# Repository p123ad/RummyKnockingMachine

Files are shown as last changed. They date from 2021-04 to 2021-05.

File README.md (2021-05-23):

# RummyKnockingMachine
 This is an Arduino-based machine that detects multiple button presses and symbolizes the first button pressed by a shining LED.
 
 It consists of 6 buttons, 6 leds and 1 piezo speaker connected to an Arduino Uno via a self designed Arduino Uno Shield.
 
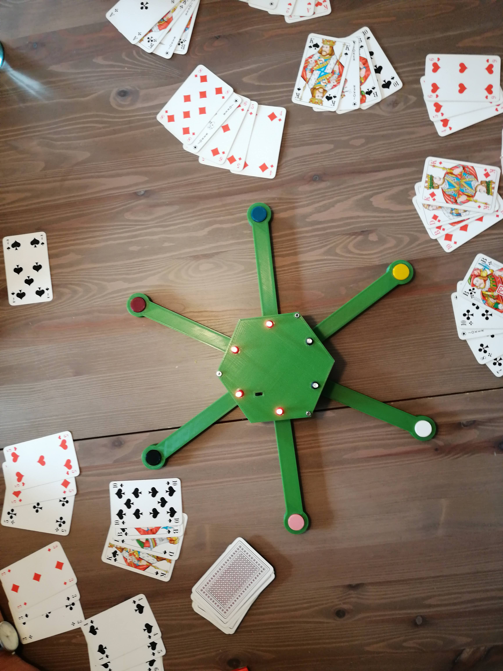
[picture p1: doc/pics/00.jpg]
RummyKnockingMachine


You can find all stls in the parts folder. They can be printed on most common 3d printers (used and stock ender 5).

The circuit diagram, breadboard diagram and the gerber files for this project are located in the electronics folder.

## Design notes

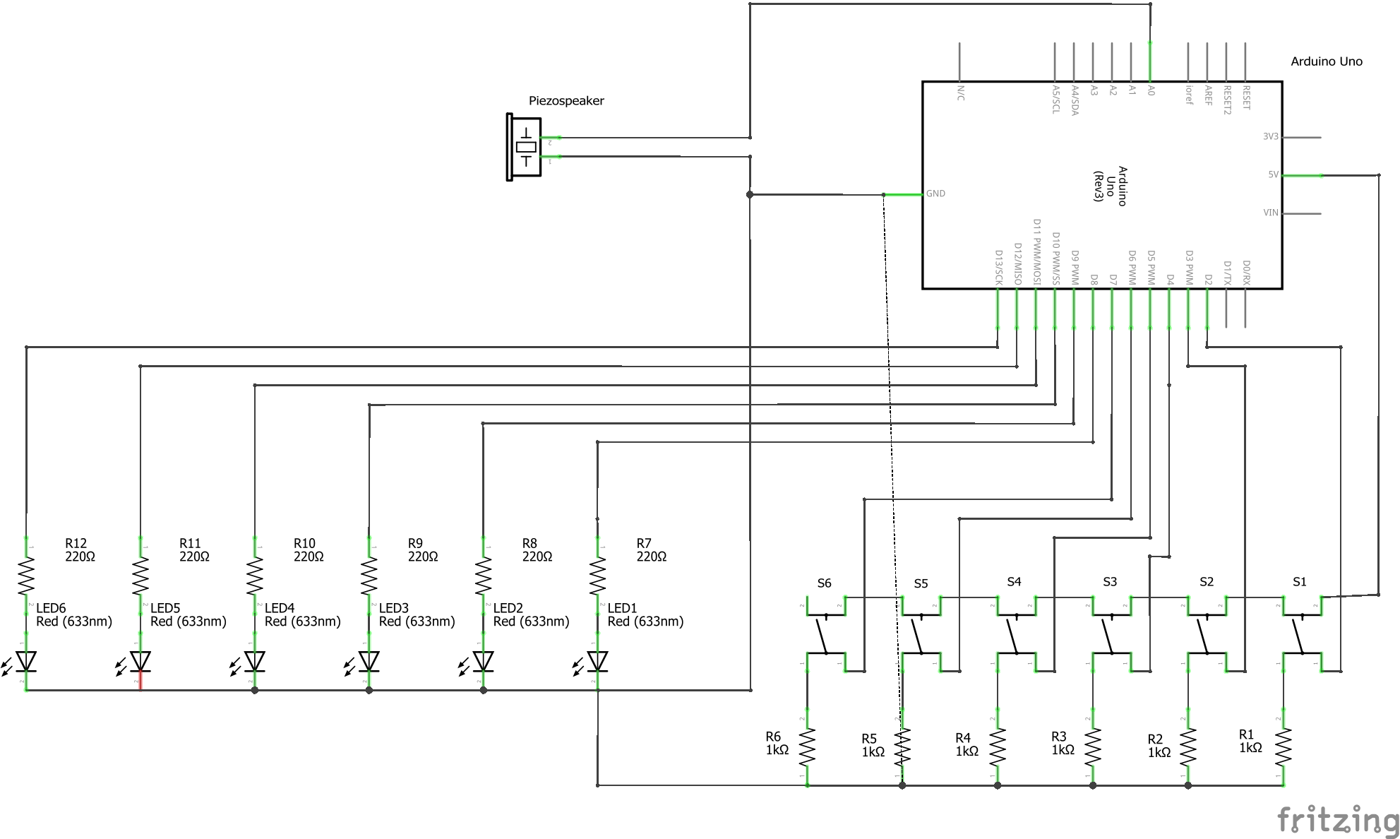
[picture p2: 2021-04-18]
electronics/circuit_diagram.png

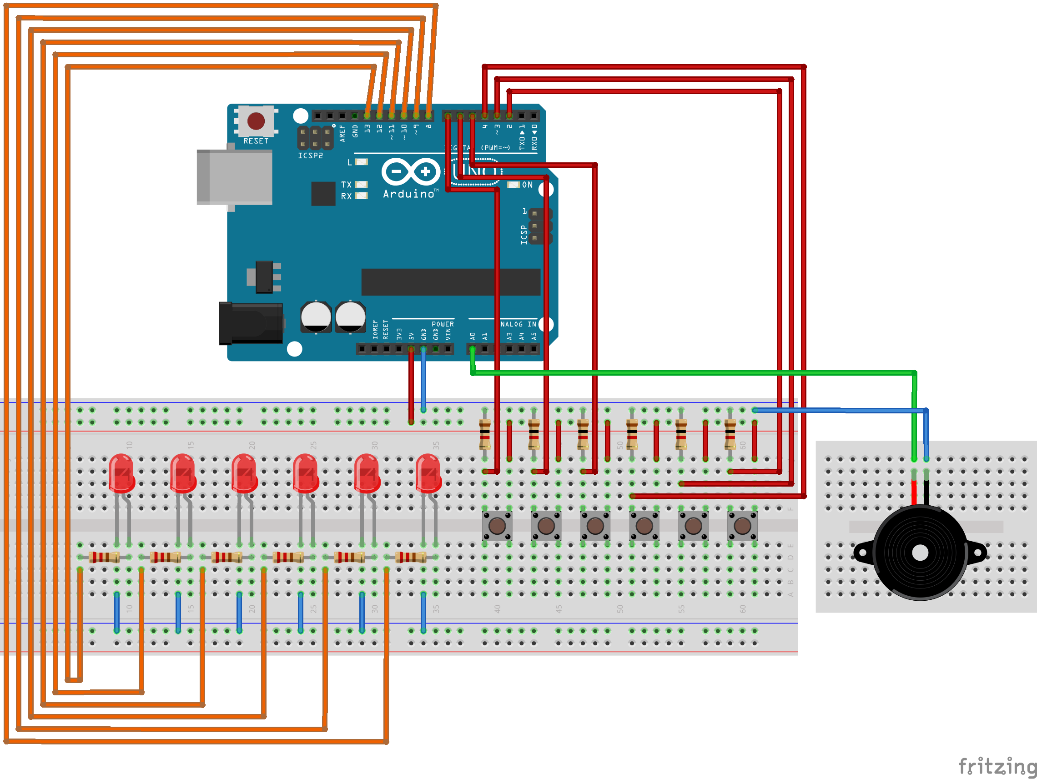
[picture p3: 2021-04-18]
electronics/breadboard_diagram.png

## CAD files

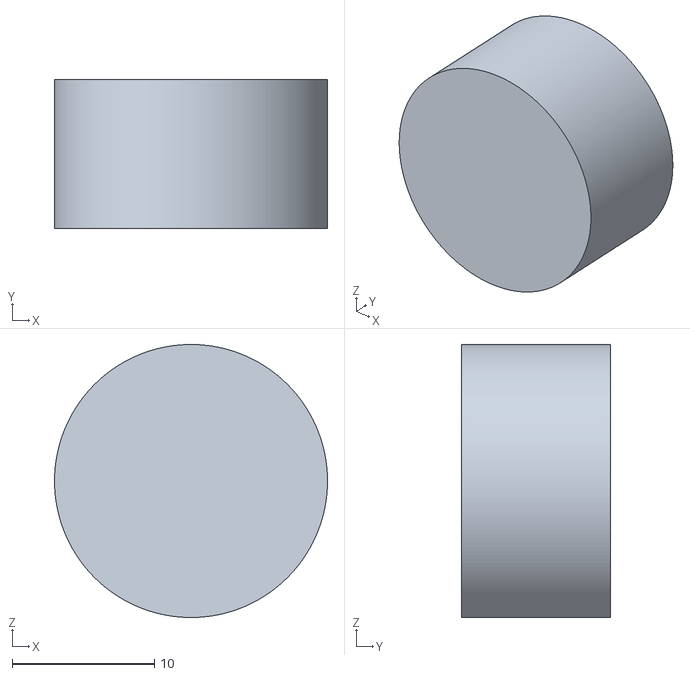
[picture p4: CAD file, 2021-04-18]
parts/stl/Knopf.stl
19.2 x 10.5 x 19.2

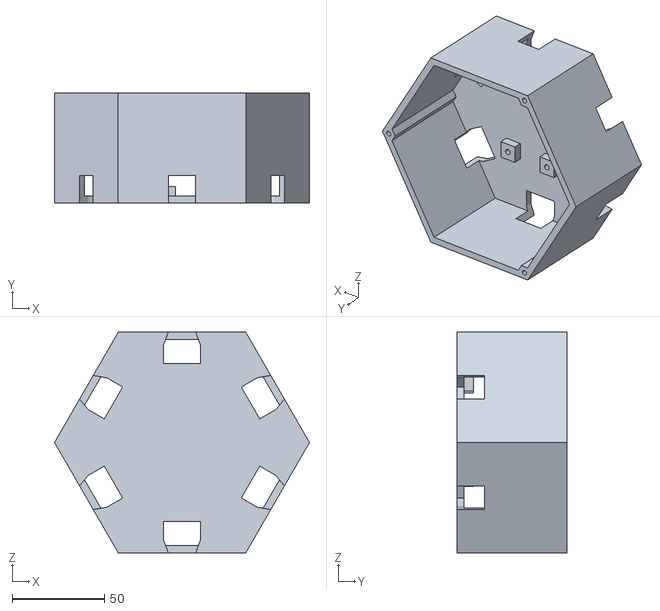
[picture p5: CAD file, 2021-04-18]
parts/stl/Box.stl
138.6 x 60.0 x 120.0

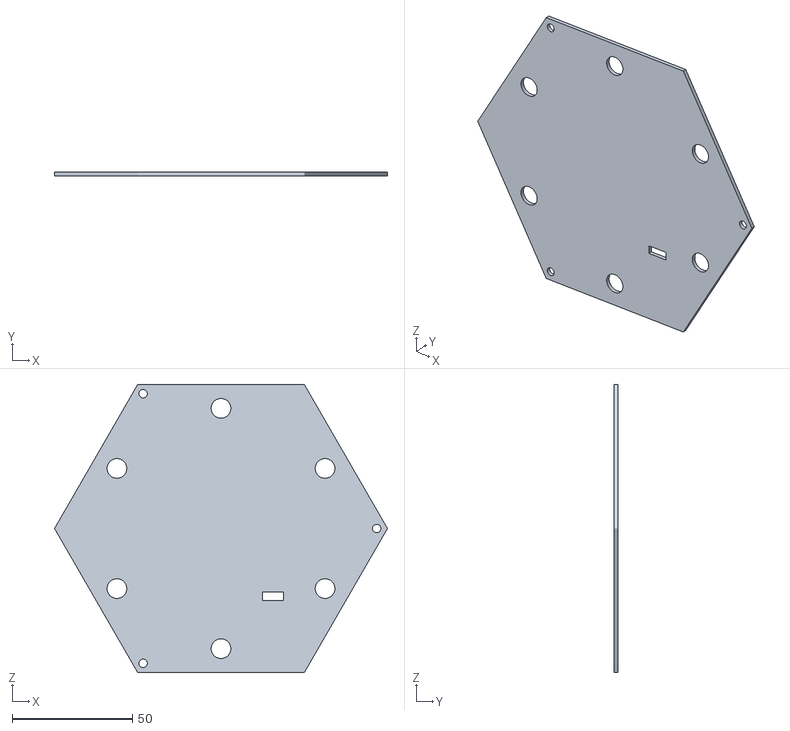
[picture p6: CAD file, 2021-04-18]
parts/stl/Lid.stl
138.6 x 1.60 x 120.0

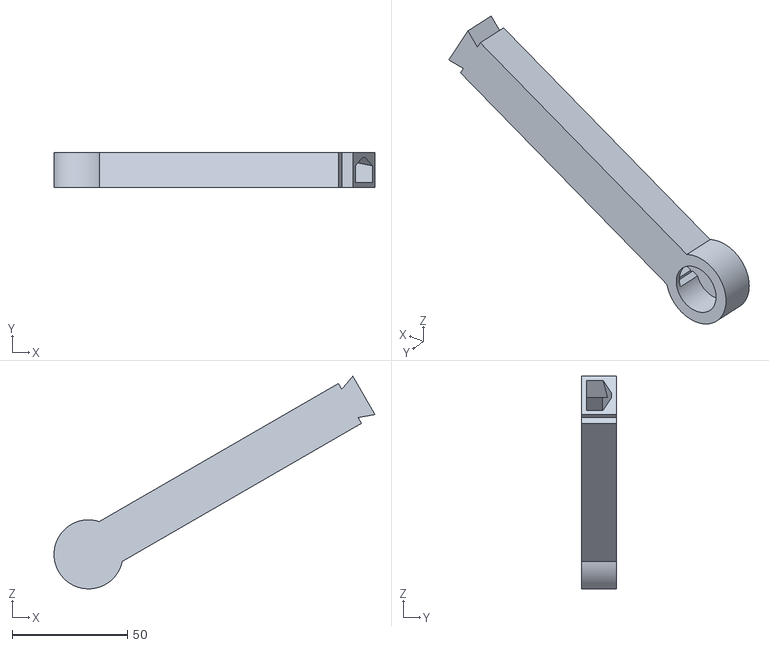
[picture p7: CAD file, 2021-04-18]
parts/stl/Arm.stl
139.5 x 15.0 x 92.4

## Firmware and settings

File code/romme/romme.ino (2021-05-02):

/**
 * Sketch für das Projekt Romme Klopfmaschine
 * 6 Spieler können haben die Taster vor sich um anzukündigen, dass eine Karte "geklopft" 
 * werden soll. Das Programm detektiert den ersten Knopfdruck und lässt die entsprechende LED
 * leuchten, während alle anderen LEDs aus bleiben.
 */
 #include "pitches.h"
 #include "button.h"
 #include "melody.h"

#define PIEZO_PIN A0

//Define Pins for Buttons and Leds
Button buttons[6] = {(2), (3), (4), (5), (6), (7)};
int leds[6] = {8, 9, 10, 11, 12, 13};



// playing a nice melody
// 1 - nice short melody
// 2 - Mario main theme
// 3 - Mario underworld theme
void playMelody(int song){
  if(song == 1) {
    int size = sizeof(simpleMelody) / sizeof(int);
    for (int thisNote = 0; thisNote < size; thisNote++) {
      // to calculate the note duration, take one second divided by the note type.
      //e.g. quarter note = 1000 / 4, eighth note = 1000/8, etc.
      int noteDuration = 1000 / simpleMelodyTempo[thisNote];
      tone(PIEZO_PIN, simpleMelody[thisNote], noteDuration);

      // to distinguish the notes, set a minimum time between them.
      // the note's duration + 30% seems to work well:
      int pauseBetweenNotes = noteDuration * 1.30;
      delay(pauseBetweenNotes);
      // stop the tone playing:
      noTone(PIEZO_PIN);
    }
  }

  if(song == 2) {
    int size = sizeof(marioMelody) / sizeof(int);
    for (int thisNote = 0; thisNote < size; thisNote++) {
      // to calculate the note duration, take one second divided by the note type.
      //e.g. quarter note = 1000 / 4, eighth note = 1000/8, etc.
      int noteDuration = 1000 / marioTempo[thisNote];
      tone(PIEZO_PIN, marioMelody[thisNote], noteDuration);

      // to distinguish the notes, set a minimum time between them.
      // the note's duration + 30% seems to work well:
      int pauseBetweenNotes = noteDuration * 1.30;
      delay(pauseBetweenNotes);
      // stop the tone playing:
      noTone(PIEZO_PIN);
    }
  }

  if(song == 3) {
    int size = sizeof(marioUnderworldMelody) / sizeof(int);
    for (int thisNote = 0; thisNote < size; thisNote++) {
      // to calculate the note duration, take one second divided by the note type.
      //e.g. quarter note = 1000 / 4, eighth note = 1000/8, etc.
      int noteDuration = 1000 / marioUnderworldTempo[thisNote];
      tone(PIEZO_PIN, marioUnderworldMelody[thisNote], noteDuration);

      // to distinguish the notes, set a minimum time between them.
      // the note's duration + 30% seems to work well:
      int pauseBetweenNotes = noteDuration * 1.30;
      delay(pauseBetweenNotes);
      // stop the tone playing:
      noTone(PIEZO_PIN);
    }
  }
}


//all Leds will blink together 3 times for a short moment
void blinkAllLeds(){
  for(int j = 0; j < 4; j++){
    for(int i = 0; i < 6; i++){
      digitalWrite(leds[i], HIGH);
      }
    delay(150);
    for(int i = 0; i < 6; i++){
      digitalWrite(leds[i], LOW);
      }
    delay(150);
  }
}

//led running light
void rotateLeds(int _delay){
  for(int i = 0; i < 6; i++){
    digitalWrite(leds[i], HIGH);
    delay(_delay);
  }
  for(int i = 0; i < 6; i++){
    digitalWrite(leds[i], LOW);
    delay(_delay);
  }
}

void setup() {
  // initialize buttons and led pins
  for(int i = 0; i < 6; i++){
    buttons[6].begin();
    pinMode(leds[i], OUTPUT);
  }

  // Initialization Show
  rotateLeds(100);
  rotateLeds(100);
  playMelody(2);
  blinkAllLeds();
  playMelody(3);

}

void loop() {
// check which button was pressed at first, then do a little winning show
  for(int i = 0; i < 6; i++){
    if(buttons[i].isPressed() == true){
      blinkAllLeds();
      playMelody(1);
      digitalWrite(leds[i], HIGH);
      delay(3000);
      rotateLeds(80);
      rotateLeds(80);
    }
  }
 
}

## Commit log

2021-04-18 upload stls
    [Arm.stl, Box.stl, Knopf.stl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]
2021-04-18 upload gerber files
    [Romme_contour.gm1, Romme_copperBottom.gbl, Romme_copperTop.gtl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]
2021-04-18 upload electronics
    [Romme_contour.gm1, Romme_copperBottom.gbl, Romme_copperTop.gtl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]
2021-05-02 fixed bug in pcb
    there was a tiny connection between GND and LED2 Out-Pin
    [Romme_Leiterplatte_contour.gm1, Romme_Leiterplatte_copperBottom.gbl, Romme_Leiterplatte_copperTop.gtl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]
2021-05-02 add arduino code
